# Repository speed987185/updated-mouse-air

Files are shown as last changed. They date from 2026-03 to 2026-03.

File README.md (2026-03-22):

# updated-mouse-air
a mouse for a blueprint submit
this a mouse project made for blueprint submission you can create your own mouse using my repo this contain all the step file :
mouse_top 
mouse_bottom
mouse_wheel
mouse_wheel_braces

#pcb
you can view or the edit the pcb using ki cad 
the pcb file name is mouse_pcb.kicad_pcb

#the required item:
required item are listed in BOM through which you can also check the prices of electronics and where to get them.

#Frimware:
the frimware is written using c language file name is mouse_frimware.h
step to flash frimware :
Hold BOOTSEL button
Plug into PC
It shows as a USB drive
Compile your code → get .uf2 file
Drag & drop .uf2 into Pico

i made this project i was in need of good mouse and i will learn too so why to use my project you can get pcb and 3d print all stl and flash the frimware and use the usb to male connector to use it to your computer.

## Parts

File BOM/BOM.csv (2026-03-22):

Items | Qty. | Price(USD) | Link
Microcontroller (Raspberry Pi Pico RP2040) | 1 | 12$ | https://www.amazon.com/gp/product/B08TVF499B/ref=ox_sc_act_image_7?smid=A2SA28G0M1VPHD&psc=1
Optical Sensor (PMW3360 salvaged) | 1 | 25$ | https://www.amazon.com/gp/product/B07YN73XN6/ref=ox_sc_act_image_6?smid=A3BZ4PFG2UQP4O
Omron D2F-01F Microswitches | 2 | 13$ | https://www.amazon.com/gp/product/B0062WNDLI/ref=ox_sc_act_image_5?smid=A20VIERU7MNN7L&psc=1
MECCANIXITY 11mm Mouse Wheel Encoder | 2 | 16$ | https://www.amazon.com/gp/product/B0C14275KR/ref=ox_sc_act_image_4?smid=A1NR50YASSZD11&psc=1
Resistor Assortment Ki | 1 | 10$ | https://www.amazon.com/gp/product/B08FD1XVL6/ref=ox_sc_act_image_3?smid=A2RFXKS6GNXFWP
Short USB to Dupont/Header Cable | 1 | 10$ | https://www.amazon.com/gp/product/B08D68JW4K/ref=ox_sc_act_image_2?smid=A2N4NU72MATLUW&psc=1
Universal PTFE Mouse Skates Dots | 2 | 13$ | https://www.amazon.com/gp/product/B0GK5DHL4T/ref=ox_sc_act_image_1?smid=AMTRPC4O50Y12
total printing cost | whole printing cost | 8$ | https://docs.google.com/document/d/1v0z8YAYk6on8Gc9-Y8T7KmDk4LBmk3RWNFWdm8gmc_I/edit?usp=sharing
pcb cost |  | 15$ | i am making it from local store

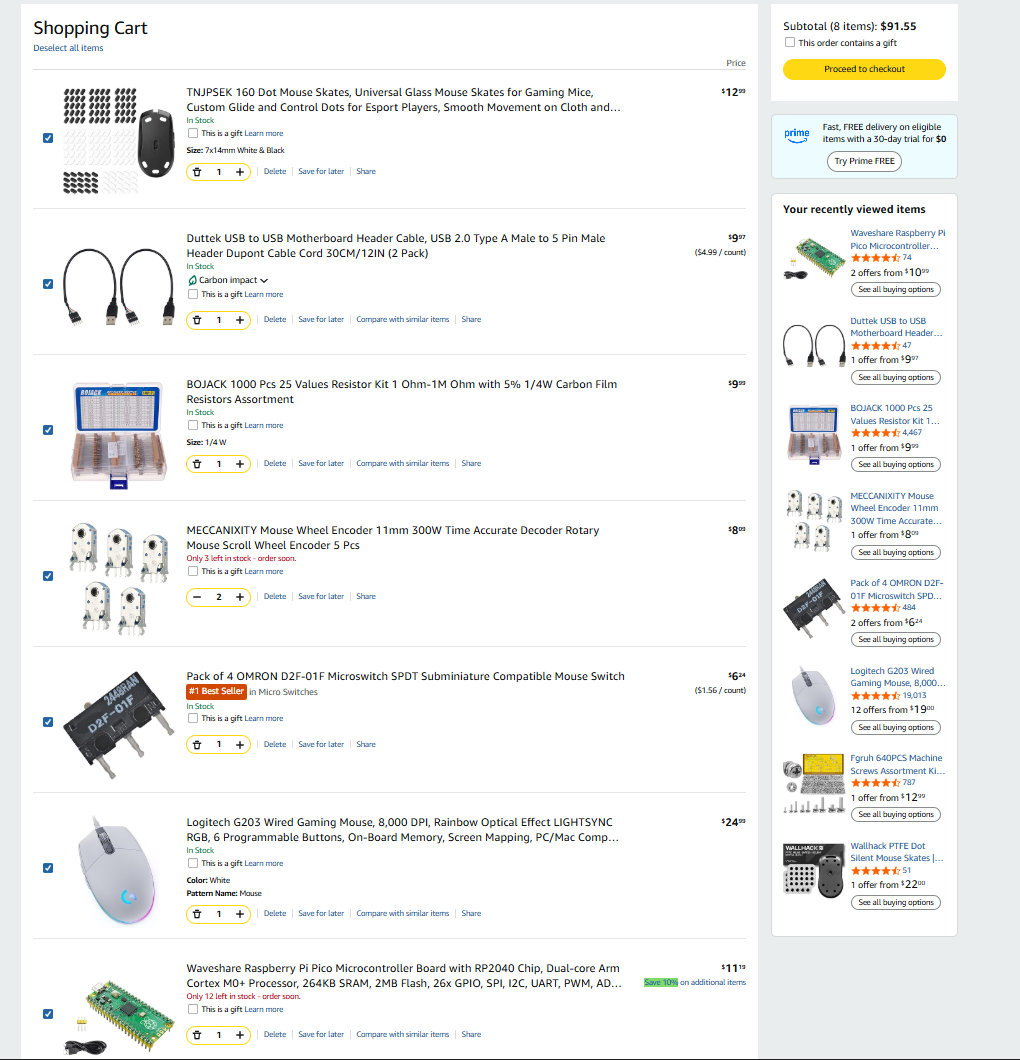
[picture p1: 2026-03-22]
BOM/Screenshot 2026-03-22 180636.png

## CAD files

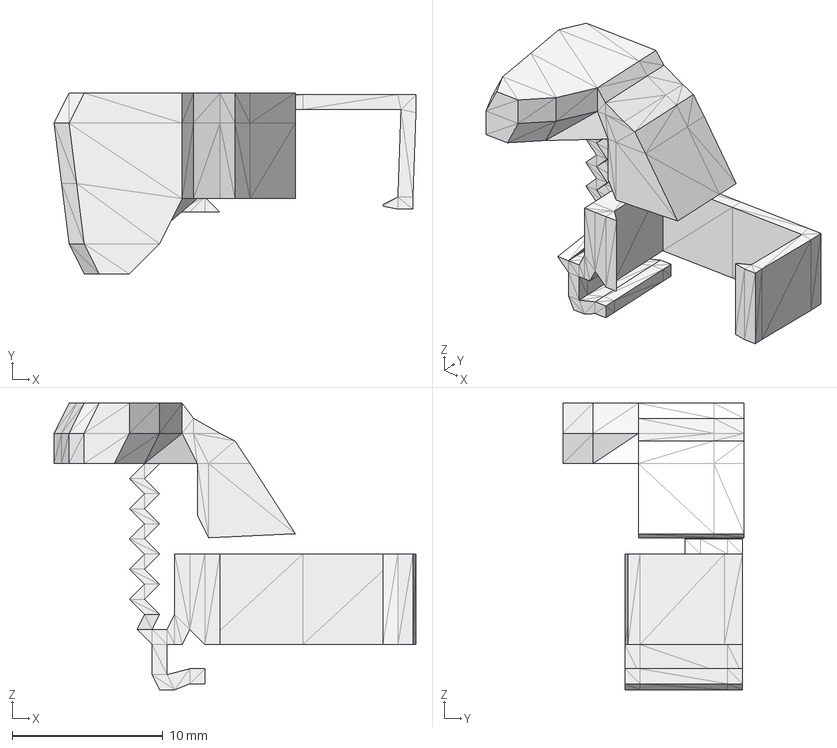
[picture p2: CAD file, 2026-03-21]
stepfile/mouse_thumb_b.step
24.0 x 12.0 x 19.0 mm

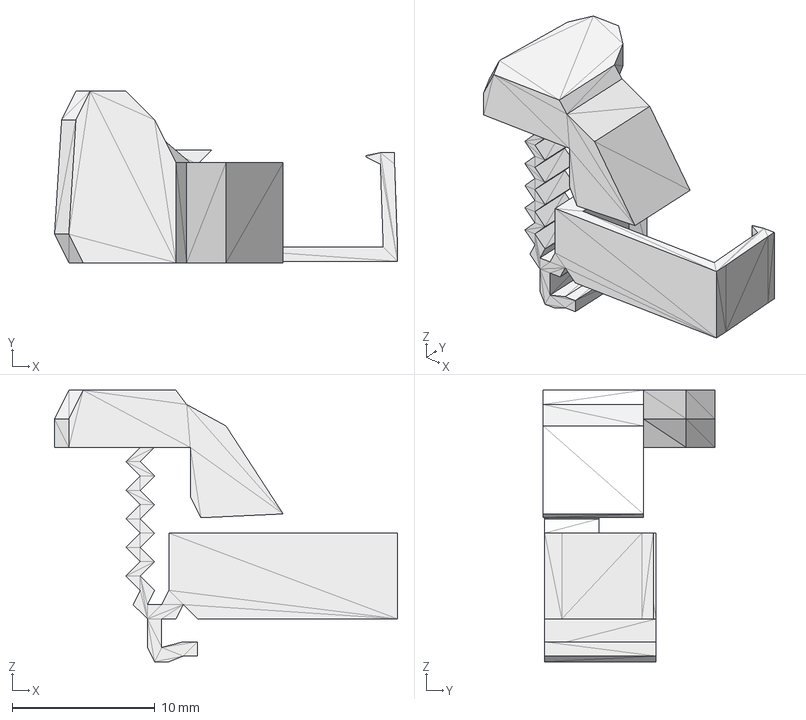
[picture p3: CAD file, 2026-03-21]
stepfile/mouse_thumb_a.step
24.0 x 12.0 x 19.0 mm

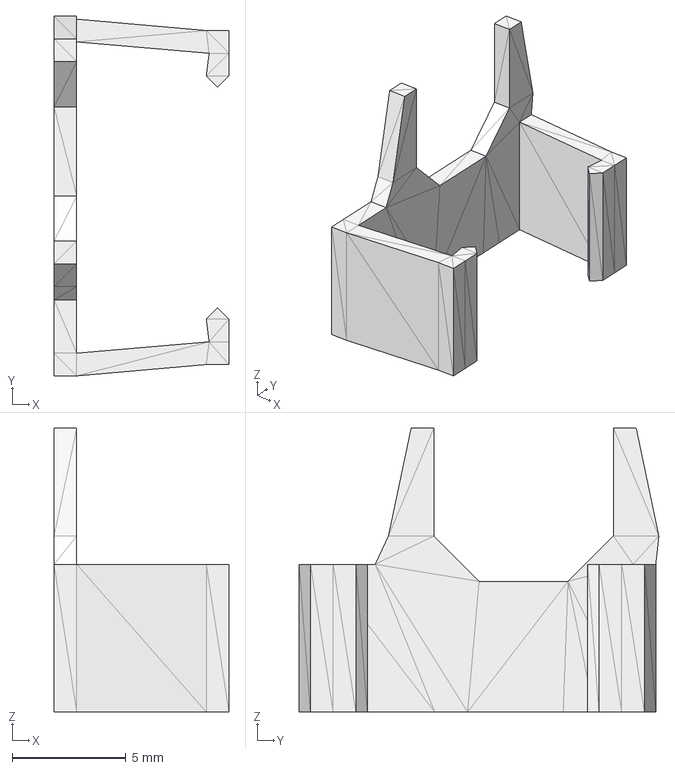
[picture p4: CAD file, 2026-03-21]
stepfile/mouse_wheel_braces.step
7.70 x 15.8 x 12.5 mm

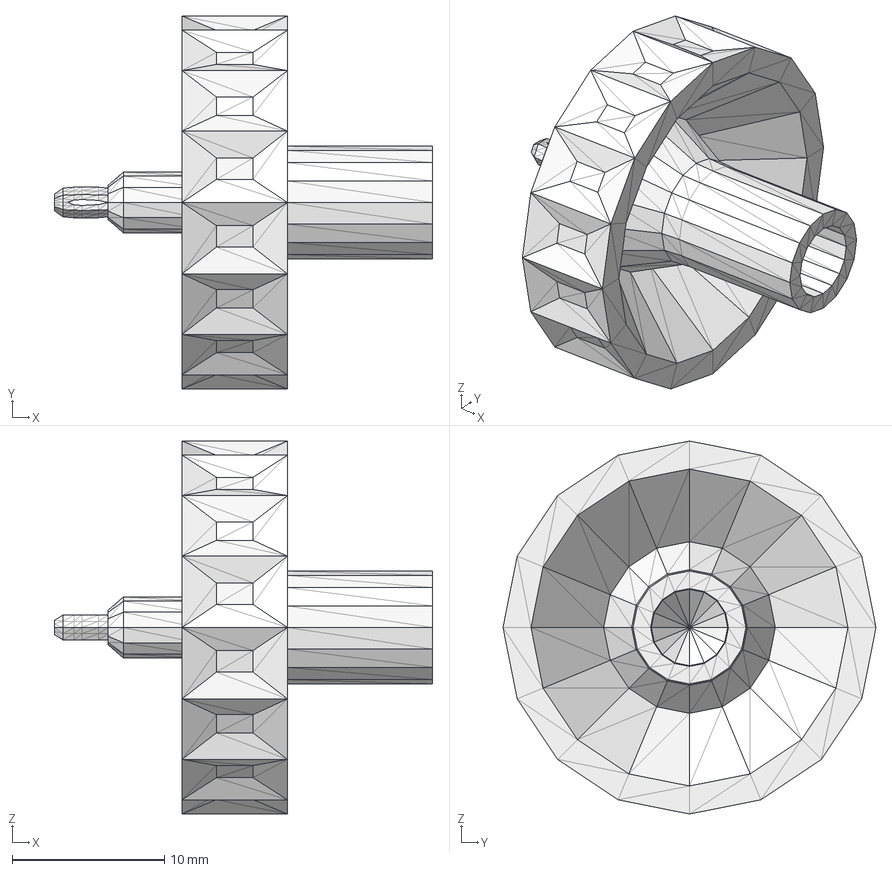
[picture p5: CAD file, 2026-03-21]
stepfile/mouse_wheel.step
24.8 x 24.5 x 24.5 mm

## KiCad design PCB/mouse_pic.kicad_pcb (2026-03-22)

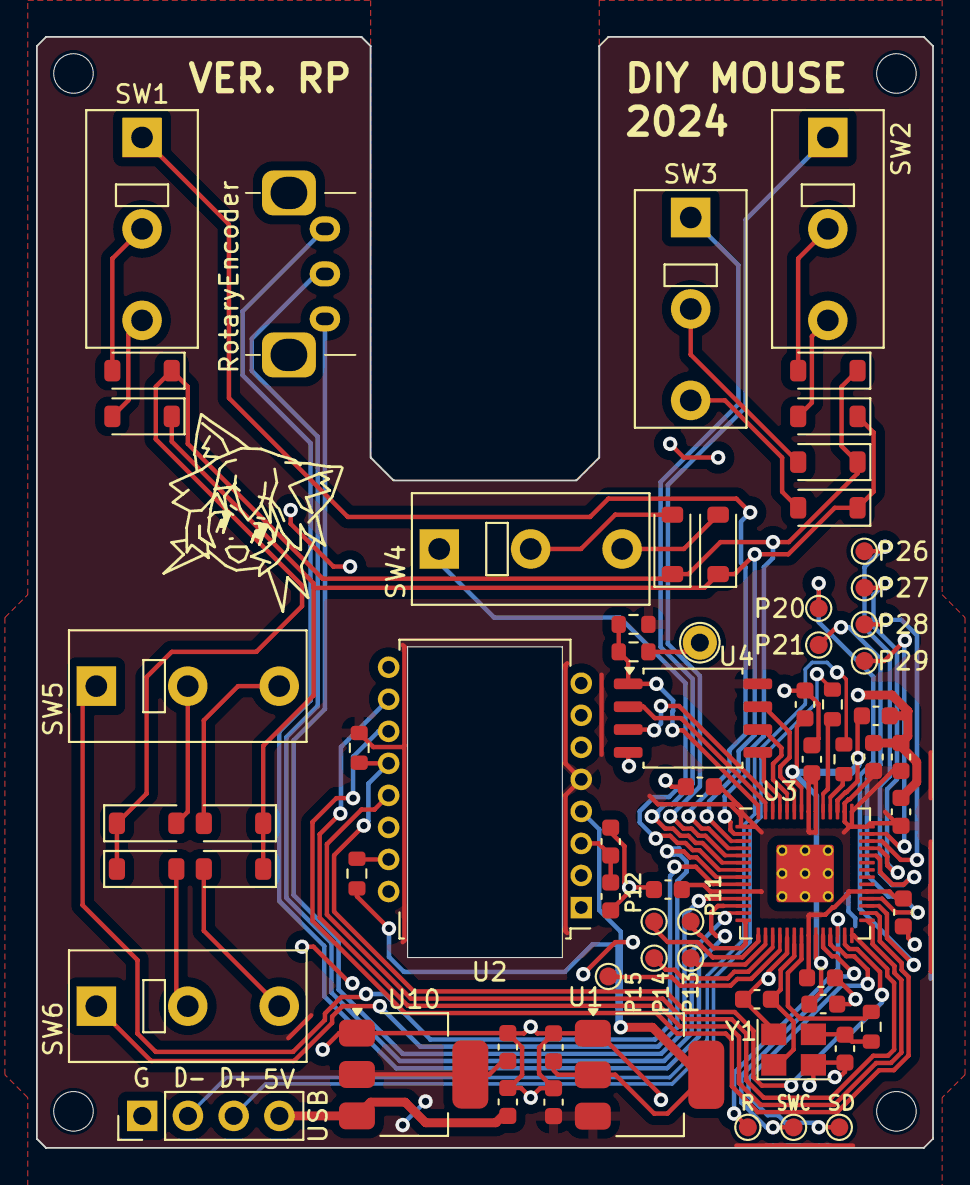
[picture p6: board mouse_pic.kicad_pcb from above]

Board: 2 copper layers, 49.8 x 61.7 mm, 67 parts (0 on the bottom side), 62 nets.

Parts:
C1, C2: 10uF; C_0603_1608Metric
C3: 100nF; C_0603_1608Metric
C4: 4.7uF; C_0603_1608Metric
C6, C7, C9, C11, C12, C13, C14, C15, C500: 100n; C_0603_1608Metric
C8, C10: 1u; C_0603_1608Metric
C100, C400: 10u; C_0603_1608Metric
C200, C300: 15p; C_0603_1608Metric
D1, D2, D3, D4, D5, D6, D7, D8, D9, D10, D11, D12: D; D_SOD-123
Encoder1: RotaryEncoder; Alps-EC10E1220501
P11, P12, P13, P14, P15, P20, P21, P26, P27, P28, P29, P30, P31, P32: TestPoint; TestPoint_Pad_D1.0mm
R1: 10K; R_0603_1608Metric
R3, R4: 27; R_0603_1608Metric
R40: R39; R_0603_1608Metric
R100, R500: 1k; R_0603_1608Metric
R200: 10k; R_0603_1608Metric
SW1, SW2, SW3, SW4, SW5, SW6: SW_SPDT; SW_Tactile_SPDT_Omron_D2F
U1: LM1117-1.8V; SOT-223-3_TabPin2
U2: PMW3360DM-T2QU; PixArt_PDIP-16_10.9x16.2mm_P1.78mm
U3: RP2040; RP2040-QFN-56
U4: W25Q32JVSS; SOIC-8_5.275x5.275mm_P1.27mm
U10: NCP1117-3.3_SOT223; SOT-223-3_TabPin2
USB1: USB; PinHeader_1x04_P2.54mm_Vertical
USB_BOOT1: Conn_01x01_Socket; TestPoint_THTPad_D2.0mm_Drill1.0mm_Edit
Y1: ABM8-272-T3; Crystal_SMD_3225-4Pin_3.2x2.5mm

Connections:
+1V1: C6.1, C7.1, C8.1, U3.23 (DVDD), U3.45 (VREG_VOUT), U3.50 (DVDD)
+3V3: C1.1, C9.1, C10.1, C11.1, C12.1, C13.1, C14.1, C15.1, C400.1, C500.1, R1.2, R200.1, U1.3 (VI), U2.5 (VDDIO), U3.1 (IOVDD), U3.10 (IOVDD), U3.22 (IOVDD), U3.33 (IOVDD), U3.42 (IOVDD), U3.43 (ADC_AVDD), U3.44 (VREG_IN), U3.48 (USB_VDD), U3.49 (IOVDD), U4.8 (VCC), U10.2 (VO)
/3360LED: R40.1, U2.15 (LED_P)
/ENC_A: Encoder1.A, U3.11 (GPIO8)
/ENC_B: Encoder1.B, U3.13 (GPIO10)
/ENC_C: Encoder1.C, U3.12 (GPIO9)
/GPIO0: D1.1 (K), D3.1 (K), D5.1 (K), D7.1 (K), D9.1 (K), D11.1 (K), U3.2 (GPIO0)
/GPIO1: D2.1 (K), D4.1 (K), D6.1 (K), D8.1 (K), D10.1 (K), D12.1 (K), U3.3 (GPIO1)
/GPIO2: SW1.2 (B), U3.4 (GPIO2)
/GPIO3: SW2.2 (B), U3.5 (GPIO3)
/GPIO4: SW3.2 (B), U3.6 (GPIO4)
/GPIO5: SW4.2 (B), U3.7 (GPIO5)
/GPIO6: SW6.2 (B), U3.8 (GPIO6)
/GPIO7: SW5.2 (B), U3.9 (GPIO7)
/GPIO11: P11.1, U3.14 (GPIO11)
/GPIO12: P12.1, U3.15 (GPIO12)
/GPIO13: P13.1, U3.16 (GPIO13)
/GPIO14: P14.1, U3.17 (GPIO14)
/GPIO15: P15.1, U3.18 (GPIO15)
/GPIO16: R1.1, U2.12 (MISO), U3.27 (GPIO16)
/GPIO17: U2.13 (NCS), U3.28 (GPIO17)
/GPIO18: U2.10 (SCLK), U3.29 (GPIO18)
/GPIO19: U2.11 (MOSI), U3.30 (GPIO19)
/GPIO20: P20.1, U3.31 (GPIO20)
/GPIO21: P21.1, U3.32 (GPIO21)
/GPIO26_ADC0: P26.1, U3.38 (GPIO26_ADC0)
/GPIO27_ADC1: P27.1, U3.39 (GPIO27_ADC1)
/GPIO28_ADC2: P28.1, U3.40 (GPIO28_ADC2)
/GPIO29_ADC3: P29.1, U3.41 (GPIO29_ADC3)
/QSPI_SCLK: U3.52 (QSPI_SCLK), U4.6 (CLK)
/QSPI_SD0: U3.53 (QSPI_SD0), U4.5 (DI(IO0))
/QSPI_SD1: U3.55 (QSPI_SD1), U4.2 (DO(IO1))
/QSPI_SD2: U3.54 (QSPI_SD2), U4.3 (IO2)
/QSPI_SD3: U3.51 (QSPI_SD3), U4.7 (IO3)
/QSPI_SS: R100.1, R200.2, U3.56 (QSPI_SS), U4.1 (~CS)
/RUN: P30.1, U3.26 (RUN)
/SWCLK: P31.1, U3.24 (SWCLK)
/SWD: P32.1, U3.25 (SWD)
/USBD+: R3.1, USB1.3
/USBD-: R4.1, USB1.2
/V2: C2.1, R40.2, U1.2 (VO), U2.4 (VDD)
/VDDPIX: C3.1, C4.1, U2.3 (VDDPIX)
/XIN: C200.1, U3.20 (XIN), Y1.1
/XOUT: R500.1, U3.21 (XOUT)
/~USB_BOOT: R100.2, USB_BOOT1.1
GND: C1.2, C2.2, C3.2, C4.2, C6.2, C7.2, C8.2, C9.2, C10.2, C11.2, C12.2, C13.2, C14.2, C15.2, C100.2, C200.2, C300.2, C400.2, C500.2, U1.1 (GND), U2.8 (GND), U3.19 (TESTEN), U3.57 (GND), U4.4 (GND), U10.1 (GND), USB1.1, Y1.2, Y1.4
unnamed: C300.1, R500.2, Y1.3
unnamed: D1.2 (A), SW1.1 (A)
unnamed: D2.2 (A), SW1.3 (C)
unnamed: D3.2 (A), SW2.1 (A)
unnamed: D4.2 (A), SW2.3 (C)
unnamed: D5.2 (A), SW3.1 (A)
unnamed: D6.2 (A), SW3.3 (C)
unnamed: D7.2 (A), SW4.1 (A)
unnamed: D8.2 (A), SW4.3 (C)
unnamed: D9.2 (A), SW5.1 (A)
unnamed: D10.2 (A), SW5.3 (C)
unnamed: D11.2 (A), SW6.1 (A)
unnamed: D12.2 (A), SW6.3 (C)
unnamed: R4.2, U3.46 (USB_DM)
unnamed: R3.2, U3.47 (USB_DP)
VBUS: C100.1, U10.3 (VI), USB1.4

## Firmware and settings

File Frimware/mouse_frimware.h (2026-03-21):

#include "USBHID.h"
#include "PlatformMutex.h"

#define REPORT_ID_MOUSE   2

#define X_MIN_REL    (-32767)
#define Y_MIN_REL    (-32767)
#define X_MAX_REL    (32767)
#define Y_MAX_REL    (32767)

class USBMouse16: public USBHID {
public:
    USBMouse16(bool connect_blocking = true, uint16_t vendor_id = 0x8234, uint16_t product_id = 0x0001, uint16_t product_release = 0x0001);

    USBMouse16(USBPhy *phy, uint16_t vendor_id = 0x8234, uint16_t product_id = 0x0001, uint16_t product_release = 0x0001);

    virtual ~USBMouse16();

    bool update(int16_t x, int16_t y, uint8_t buttons, int8_t z);
    
    virtual const uint8_t *report_desc();

protected:
    virtual const uint8_t *configuration_desc(uint8_t index);

private:
    uint8_t _configuration_descriptor[41];
    PlatformMutex _mutex;

};

#include "stdint.h"
#include "ThisThread.h"
#include "usb_phy_api.h"

using namespace arduino;
using namespace std::chrono_literals;

USBMouse16::USBMouse16(bool connect_blocking, uint16_t vendor_id, uint16_t product_id, uint16_t product_release):
    USBHID(get_usb_phy(), 0, 0, vendor_id, product_id, product_release)
{
}

USBMouse16::USBMouse16(USBPhy *phy, uint16_t vendor_id, uint16_t product_id, uint16_t product_release):
    USBHID(get_usb_phy(), 0, 0, vendor_id, product_id, product_release)
{
}

USBMouse16::~USBMouse16()
{
}

bool USBMouse16::update(int16_t x, int16_t y, uint8_t buttons, int8_t z)
{
    _mutex.lock();

    HID_REPORT report;
    report.data[0] = buttons;
    report.data[1] = (uint8_t)(x);
    report.data[2] = (uint8_t)(((uint16_t)x) >> 8);
    report.data[3] = (uint8_t)(y);
    report.data[4] = (uint8_t)(((uint16_t)y) >> 8);
    report.data[5] = -z; // >0 to scroll down, <0 to scroll up

    report.length = 6;

    bool ret = send(&report);

    _mutex.unlock();
    return ret;
}

const uint8_t *USBMouse16::report_desc()
{
    static const uint8_t report_descriptor[] = {
        USAGE_PAGE(1),      0x01,       // Genric Desktop
        USAGE(1),           0x02,       // Mouse
        COLLECTION(1),      0x01,       // Application
        USAGE(1),           0x01,       // Pointer
        COLLECTION(1),      0x00,       // Physical

        // Buttons
        REPORT_COUNT(1),    0x05,
        REPORT_SIZE(1),     0x01,
        USAGE_PAGE(1),      0x09,
        USAGE_MINIMUM(1),       0x01,
        USAGE_MAXIMUM(1),       0x05,
        LOGICAL_MINIMUM(1),     0x00,
        LOGICAL_MAXIMUM(1),     0x01,
        INPUT(1),           0x02,
        // Padding
        REPORT_COUNT(1),    0x01,
        REPORT_SIZE(1),     0x03,
        INPUT(1),           0x01,

        REPORT_COUNT(1),    2,
        REPORT_SIZE(1),     16,
        USAGE_PAGE(1),      1,
        USAGE(1),           0x30,       // X
        USAGE(1),           0x31,       // Y
        LOGICAL_MINIMUM(2),     0x01, 0x80,
        LOGICAL_MAXIMUM(2),     0xff, 0x7f,
        INPUT(1),           0x06,       // Relative data
        
        REPORT_COUNT(1),    1,
        REPORT_SIZE(1),     8,
        USAGE_PAGE(1),      1,
        USAGE(1),           0x38,       // scroll
        LOGICAL_MINIMUM(1),     0x81,
        LOGICAL_MAXIMUM(1),     0x7f,
        INPUT(1),           0x06,       // Relative data

        END_COLLECTION(0),
        END_COLLECTION(0),
    };
    reportLength = sizeof(report_descriptor);
    return report_descriptor;
}

#define DEFAULT_CONFIGURATION (1)
#define TOTAL_DESCRIPTOR_LENGTH ((1 * CONFIGURATION_DESCRIPTOR_LENGTH) \
                               + (1 * INTERFACE_DESCRIPTOR_LENGTH) \
                               + (1 * HID_DESCRIPTOR_LENGTH) \
                               + (2 * ENDPOINT_DESCRIPTOR_LENGTH))

const uint8_t *USBMouse16::configuration_desc(uint8_t index)
{
    if (index != 0) {
        return NULL;
    }
    uint8_t configuration_descriptor_temp[] = {
        CONFIGURATION_DESCRIPTOR_LENGTH,    // bLength
        CONFIGURATION_DESCRIPTOR,           // bDescriptorType
        LSB(TOTAL_DESCRIPTOR_LENGTH),       // wTotalLength (LSB)
        MSB(TOTAL_DESCRIPTOR_LENGTH),       // wTotalLength (MSB)
        0x01,                               // bNumInterfaces
        DEFAULT_CONFIGURATION,              // bConfigurationValue
        0x00,                               // iConfiguration
        C_RESERVED | C_SELF_POWERED,        // bmAttributes
        C_POWER(0),                         // bMaxPower

        INTERFACE_DESCRIPTOR_LENGTH,        // bLength
        INTERFACE_DESCRIPTOR,               // bDescriptorType
        0x00,                               // bInterfaceNumber
        0x00,                               // bAlternateSetting
        0x02,                               // bNumEndpoints
        HID_CLASS,                          // bInterfaceClass
        HID_SUBCLASS_BOOT,                  // bInterfaceSubClass
        HID_PROTOCOL_MOUSE,                 // bInterfaceProtocol
        0x00,                               // iInterface

        HID_DESCRIPTOR_LENGTH,              // bLength
        HID_DESCRIPTOR,                     // bDescriptorType
        LSB(HID_VERSION_1_11),              // bcdHID (LSB)
        MSB(HID_VERSION_1_11),              // bcdHID (MSB)
        0x00,                               // bCountryCode
        0x01,                               // bNumDescriptors
        REPORT_DESCRIPTOR,                  // bDescriptorType
        (uint8_t)(LSB(report_desc_length())), // wDescriptorLength (LSB)
        (uint8_t)(MSB(report_desc_length())), // wDescriptorLength (MSB)

        ENDPOINT_DESCRIPTOR_LENGTH,         // bLength
        ENDPOINT_DESCRIPTOR,                // bDescriptorType
        _int_in,                            // bEndpointAddress
        E_INTERRUPT,                        // bmAttributes
        LSB(MAX_HID_REPORT_SIZE),           // wMaxPacketSize (LSB)
        MSB(MAX_HID_REPORT_SIZE),           // wMaxPacketSize (MSB)
        1,                                  // bInterval (milliseconds)

        ENDPOINT_DESCRIPTOR_LENGTH,         // bLength
        ENDPOINT_DESCRIPTOR,                // bDescriptorType
        _int_out,                           // bEndpointAddress
        E_INTERRUPT,                        // bmAttributes
        LSB(MAX_HID_REPORT_SIZE),           // wMaxPacketSize (LSB)
        MSB(MAX_HID_REPORT_SIZE),           // wMaxPacketSize (MSB)
        1,                                  // bInterval (milliseconds)
    };
    MBED_ASSERT(sizeof(configuration_descriptor_temp) == sizeof(_configuration_descriptor));
    memcpy(_configuration_descriptor, configuration_descriptor_temp, sizeof(_configuration_descriptor));
    return _configuration_descriptor;
}

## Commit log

2026-03-21 Enhance README with project details and requirements
    Expanded project description and added details about PCB, required items, and firmware.
2026-03-22 Add files via upload
    cart picture wihout pcb
2026-03-22 Rename Screenshot 2026-03-22 180636.png to BOM/Screenshot 2026-03-22 180636.png
2026-03-22 Add files via upload
    pcb board
    [mouse_pic.kicad_pcb]
